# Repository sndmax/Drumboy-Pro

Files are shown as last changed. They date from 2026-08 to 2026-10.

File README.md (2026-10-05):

# Drumboy Pro

📖 **[Developer Wiki](https://www.randomwaves.io/drumboy-pro/drumboy-pro-wiki.html)** — full hardware specs, schematics walkthrough, firmware architecture, DSP internals, and memory map.

**An open-source hardware groovebox** — sequencer, sampler, and DSP effects engine built around an STM32H723 (Cortex-M7 @ 550 MHz), with a 540×960 touch-free color display, 42 keys, 8 rotary encoders, and full MIDI/Sync I/O.

This repository holds the complete hardware design (KiCad) and firmware (STM32CubeIDE / C++) for Drumboy Pro, released by [Randomwaves](https://randomwaves.io) as an open hardware/software project.

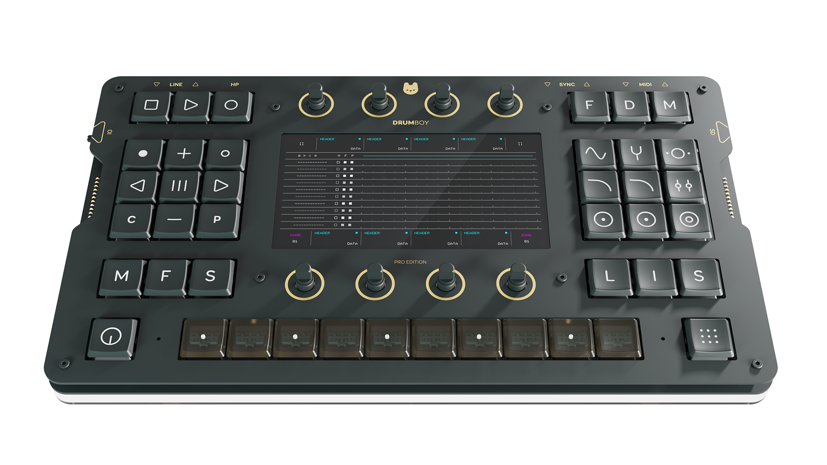
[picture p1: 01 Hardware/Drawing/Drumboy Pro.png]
Drumboy Pro


---

## Overview

The MCU sits at the center of six subsystems: an NT35510 display driven over a 16-bit parallel GPIO bus, 16 MB of external SDRAM for sample streaming, an SGTL5000 audio codec over I2S/I2C, a microSD card for storage, a control surface fanned out over six MCP23017 I/O expanders, and external connectivity (MIDI, Sync, USB-C power).

| | |
|---|---|
| **MCU** | STM32H723ZGT6 — Cortex-M7 @ 550 MHz (VOS0), LQFP-144 |
| **Display** | NT35510, 540×960, 16-bit parallel |
| **SDRAM** | 16 MB (IS42S16800J-7TL-TR), FMC bus |
| **Audio codec** | SGTL5000 — I2S3 audio / I2C3 control |
| **Storage** | microSD (TF-01A), SDMMC2, FAT filesystem |
| **Control surface** | 42 keys, 42 LEDs, 8 rotary encoders — 6× MCP23017 over I2C |
| **Connectivity** | MIDI In/Out, Sync In/Out, USB-C power |
| **Flash** | 1024 KB, split between bootloader and application |

## Features

- **10 sample layers**, each independently modulated by a 10-slot LFO matrix (sample-and-hold at note-trigger time)
- **Per-layer routing** into a shared DSP chain: parametric EQ → 2× multimode filter → 2× send effect → stereo reverb
- **9 effect types** per send slot: Delay, Chorus, Flanger, Phaser, Compressor, Expander, Overdrive, Distortion, Bitcrusher
- **Freeverb/Schroeder-Moorer style reverb** with pre-delay, stereo surround derivation, and nine built-in profiles: Default, Tight, Snap, Chamber, Warehouse, Disco, Dub, Ghost, Texture
- **Sequencer** with 5 song banks per layer, 64 beats per bank, and algorithmic complex-fill generation (timing alignment × level curve templates)
- Hold **Copy** while increasing **Bars** to double the bar count (for example, 2 → 4) and duplicate the entire current song bank across all instruments. Doubling must fit the song-length limit; each bank supports 64 beats and 32 complex fills.
- **MIDI In/Out** (opto-isolated input) and **Sync In/Out** for external clock/gate sync
- **SD-card firmware updates** via a dedicated bootloader with CRC-32 verified staged writes
- Fully open hardware (KiCad) and firmware (C/C++ against the STM32 HAL) — no CMSIS-DSP or external DSP library, all hand-rolled biquad/delay-line DSP on the Cortex-M7 FPU

Choose **Profile** with the second encoder in the Reverb menu or select the field with left/right and change it with up/down. Each profile enables reverb and applies its complete settings through a bypass transition. **Tight** is the starting profile at initialization and for new projects and drumkits. **Default** retains the original settings for an explicit reverb reset and recovery from invalid saved parameters.

| Profile | Intended use | Size | Decay | Damping | PreDelay (ms) | Surround (%) | Dry | Wet |
|---|---|---:|---:|---:|---:|---:|---:|---:|
| Default | Original reset settings | 25 | 50 | 30 | 5 | 25 | 100 | 50 |
| Tight | Techno/house grooves, hats and shakers | 25 | 32 | 65 | 8 | 25 | 100 | 18 |
| Snap | Breakbeat, fast snare/clap and percussion | 10 | 15 | 40 | 10 | 10 | 100 | 18 |
| Chamber | Dark hypnotic percussion, rims and toms | 38 | 55 | 70 | 3 | 30 | 100 | 25 |
| Warehouse | Sparse hits, rides and transitions | 68 | 40 | 60 | 20 | 40 | 100 | 25 |
| Disco | Brighter house/Italo claps, snares and stabs | 40 | 50 | 25 | 20 | 30 | 100 | 30 |
| Dub | Leftfield accents and delay into reverb | 52 | 70 | 75 | 30 | 40 | 100 | 35 |
| Ghost | Wet textures with a shorter tail | 72 | 80 | 70 | 4 | 65 | 0 | 100 |
| Texture | Long atmospheric tails and transitions | 100 | 100 | 65 | 40 | 80 | 0 | 100 |

**Ghost** and **Texture** use Dry 0% / Wet 100% on the shared reverb bus: every source routed into reverb loses its direct signal. For a dedicated texture, route only the intended sources into that bus. Manual edits display **Custom** unless all settings match a built-in profile; the global Size encoder assignment remains available. Projects and drumkits keep the existing file format and restore the profile name from the saved settings. Older Room, Hall, Dark and Ambient settings load as Custom with their parameters preserved.

## Repository structure

```
01 Hardware/
  Main/       KiCad project — main board (Drumboy_Main)
  Top/        KiCad project — top/control-surface board (Drumboy_Top)
  Drawing/    Mechanical drawings, enclosure models, graphics, fonts

02 Software/
  Drumboy-Pro-Boot-H723/   Bootloader — STM32CubeIDE project (own repo, linked below)
  Drumboy-Pro-App-H723/    Application firmware — STM32CubeIDE project (own repo, linked below)
  Firmware/                 Prebuilt firmware binaries
  Sd Card/                  Reference SD card contents (samples, presets, drumkits, system data)
```

### Related repositories

Firmware is split into two independently-built projects that share one flash device — a bad application build can never brick the update path:

| Project | Responsibility |
|---|---|
| [Drumboy-Pro-Boot-H723](https://github.com/Randomwaves-Team/Drumboy-Pro-Boot-H723) | Checks the SD card for a firmware package, validates and programs it, then jumps to the application |
| [Drumboy-Pro-App-H723](https://github.com/Randomwaves-Team/Drumboy-Pro-App-H723) | The sequencer, DSP engine, UI, and all runtime behavior |

## Hardware

Designed in **KiCad 7**. Open `01 Hardware/Main/Drumboy_Main.kicad_pro` for the main board, or `01 Hardware/Top/Drumboy_Top.kicad_pro` for the control-surface board. All third-party symbols, footprints, and 3D models are vendored under each project's `Library/` folder.

Mechanical design (enclosure and 3D model) lives in `01 Hardware/Drawing/` as **Rhinoceros 8** files — `Drumboy Pro 2D.3dm` and `Drumboy Pro 3D.zip` (zipped to keep it under GitHub's file size limit; unzip to get the `.3dm`).

A full BOM is generated from KiCad at `production/bom.csv`. See the [wiki](https://www.randomwaves.io/drumboy-pro/drumboy-pro-wiki.html) for the annotated schematic walkthrough, clock tree, power-domain isolation scheme, and key component reference.

## Firmware

Built with **STM32CubeIDE**, written in C/C++ against the STM32 HAL.

- Bootloader owns flash sector 0 (`0x08000000`–`0x0801FFFF`)
- Application owns sectors 1–7 (`0x08020000`–`0x080FFFFF`), with the vector table relocated at startup

To flash over SWD, wire an ST-Link V2 to the board's `SWDIO` (PA13), `SWCLK` (PA14), and `GND` pins, then build and flash from STM32CubeIDE. See the wiki's [Build, Flash & Debug](https://www.randomwaves.io/drumboy-pro/drumboy-pro-wiki.html) section for details.

## License

Released under the [MIT License](LICENSE).

## Community

- 💬 [Discord community](https://discord.gg/5atevNH6UU) — join the discussion
- 🌐 [randomwaves.io](https://www.randomwaves.io)
- ✉️ [hello@randomwaves.io](mailto:hello@randomwaves.io)

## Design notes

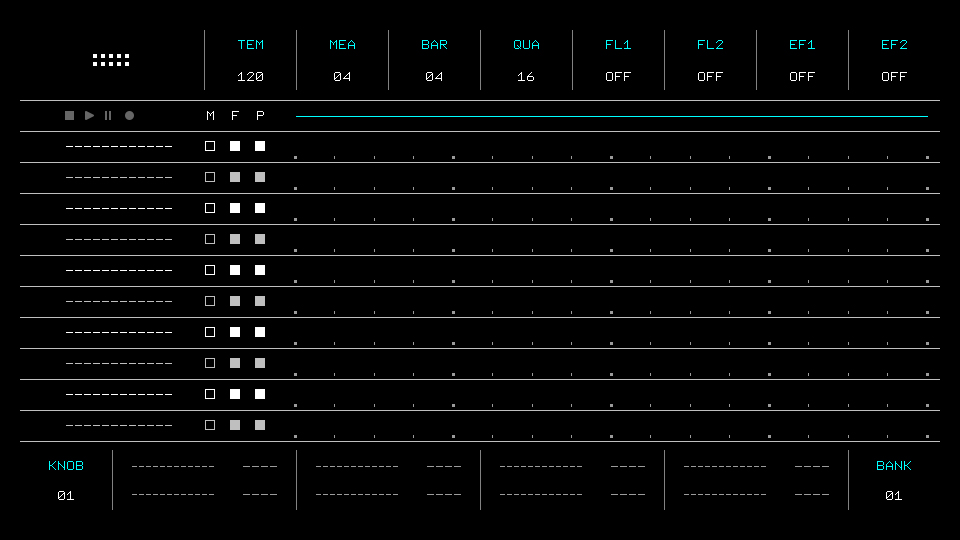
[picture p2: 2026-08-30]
01 Hardware/Drawing/Drumboy Pro Screen.jpg

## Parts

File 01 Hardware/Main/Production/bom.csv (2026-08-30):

Designator | Footprint | Quantity | Value | LCSC Part #
C1, C10, C11, C12, C16, C2, C20, C23, C26, C28, C3, C30, C32, C33, C34, C35, C36, C37, C38, C4, C41, C42, C44, C45, C47, C49, C5, C51, C53, C55, C57, C59, C6, C61, C63, C65, C67, C68, C7, C71, C8, C9 | 603 | 42 | 0.1uF
C13, C17, C27, C29, C31, C39, C48, C50, C52, C54, C56, C58, C72 | 603 | 13 | 4.7uF
C14, C18, C60, C62, C64, C66 | 603 | 6 | 2.2uF
C15, C19 | 603 | 2 | 33pF
C21, C24, C40, C69, C70, C73, C75 | 603 | 7 | 1uF
C22, C25, C43, C46 | 603 | 4 | 10uF
C77, C78, C79, C80, C81, C82, C83, C84, C85, C86, C87, C88, C89, C90, C91, C92 | 603 | 16 | 0.01uF
D1, D2, D3, D39, D4, D40, D41, D42, D43, D44 | 402 | 10 | LED G | C130722
D10 | D_SOD-523 | 1 | 1N4148WT | C27748
D11, D14, D17, D20, D23, D26, D29, D32, D35, D38 | 603 | 10 | LED W | C158100
D12, D13, D15, D16, D18, D19 | 402 | 6 | LED R | C130719
D21, D22, D24, D25, D27, D28, D7, D8 | 402 | 8 | LED O | C130720
D30, D31, D33, D34, D36, D37, D5, D6 | 402 | 8 | LED Y | C130721
D9 | SOD3716X135N | 1 | MBR0520LT3G | C165467
F1 | 805 | 1 | MF-PSMF075X-2 | C116173
FB1, FB2 | 603 | 2 | BLM18AG102SN1D | C85824
FB3, FB4, FB5, FB6, FB7, FB8, FB9 | 603 | 7 | BLM18AG601SN1D | C19330
IC1 | SOP80P1176X120-54N | 1 | IS42S16800J-7TL-TR | C2063470
IC2 | QFP50P2200X2200X160-144N | 1 | STM32H723ZGT6 | C730146
IC3 | SOT95P280X100-5N | 1 | MP3302DJ-LF-Z | C15035
IC4, IC5 | SOT95P285X140-5N | 2 | AP2112K-3.3TRG1 | C51118
IC6 | SOT95P285X140-5N | 1 | AP2112K-1.8TRG1 | C176944
IC7 | QFN50P500X500X90-33N | 1 | SGTL5000XNBA3R2 | C511764
J1 | TYPEC31M17 | 1 | TYPE-C-31-M-17 | C283540
J10, J4, J5, J6, J7, J8, J9 | SJ13515SMTTR | 7 | SJ1-3515-SMT-TR | C92633
J2 | HIROSE_FH26W-51S-0.3SHW_60_ | 1 | FH26W-51S-0.3SHW_60_ | C424656
J3 | M208890345 | 1 | M20-8890345 | C5242196
L1 | NRS5024T4R7MMGJ | 1 | NRS5024T4R7MMGJ | C2043431
MICRO_SD | TF-01A | 1 | TF-01A | C91145
R1, R2 | 603 | 2 | 5.1K
R10, R100, R101, R102, R103, R104, R105, R106, R107, R108, R109, R110, R111, R112, R113, R114, R115, R116, R117, R118, R119, R12, R120, R121, R122, R16, R23, R24, R25, R26, R28, R29, R32, R36, R37, R38, R39, R4, R40, R41, R42, R43, R44, R45, R46, R47, R81, R82, R83, R84, R85, R86, R87, R88, R99 | 603 | 55 | 10K
R11, R14, R17, R20, R56, R57, R6, R60, R61, R64, R65, R67, R68, R70, R71, R73, R74, R76, R77, R79, R8, R80, R9, R90, R91, R93, R94, R95, R96, R97, R98 | 603 | 31 | 2.2K
R13, R7 | 603 | 2 | 100K
R15, R18, R19, R21, R22 | 603 | 5 | 47K
R27 | 603 | 1 | 10
R3, R55, R59, R63, R66, R69, R72, R75, R78, R89, R92 | 603 | 11 | 3.3K
R30, R31, R48 | 603 | 3 | 220
R33, R34, R35, R50, R51, R52, R54 | 603 | 7 | 0
R49 | 603 | 1 | 100
R5 | 603 | 1 | 4.7
R53 | 603 | 1 | 470
R58, R62 | 603 | 2 | 47
S1 | SC12PAQR | 1 | SC12P-AQR | C240300
S2, S3 | 431481031816 | 2 | 431481031816
SW1, SW10, SW11, SW12, SW13, SW14, SW15, SW16, SW17, SW18, SW19, SW2, SW20, SW21, SW22, SW23, SW24, SW25, SW26, SW27, SW28, SW29, SW3, SW30, SW31, SW32, SW33, SW34, SW35, SW36, SW37, SW38, SW39, SW4, SW40, SW41, SW42, SW5, SW6, SW7, SW8, SW9 | SW_PG1350 | 42 | SW_Push
U1, U2, U3, U4, U5, U6 | QFN65P600X600X100-29N-D | 6 | MCP23017_ML | C629439
U10, U11, U12, U13, U14, U15, U8, U9 | PEC12R4017FN0024 | 8 | PEC12R-4017F-N0024
U7 | SMDIP-6_W9.53mm | 1 | H11L1 | C78589
Y1 | ABM7 | 1 | ABM7-8MHZ-D2Y-T | C596892

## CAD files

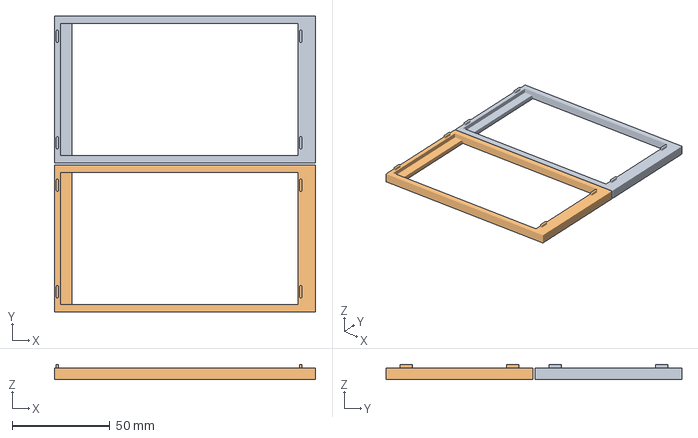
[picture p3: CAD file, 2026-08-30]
01 Hardware/Drawing/Drumboy Pro LCD.3mf
133.5 x 151.4 x 7.80 mm

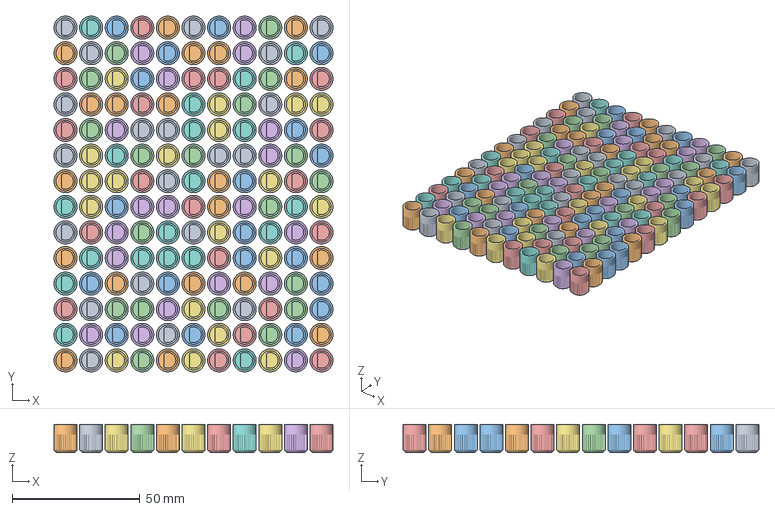
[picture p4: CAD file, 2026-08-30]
01 Hardware/Drawing/Drumboy Pro Knob.3mf
109.0 x 139.0 x 11.0 mm

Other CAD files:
01 Hardware/Drawing/Drumboy Pro 2D.3dm

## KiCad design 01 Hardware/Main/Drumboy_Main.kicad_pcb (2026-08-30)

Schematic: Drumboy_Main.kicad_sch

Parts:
C1, C2, C3, C4, C5, C6, C7, C8, C9, C10, C11, C12, C16, C20, C23, C26, C28, C30, C32, C33, C34, C35, C36, C37, C38, C41, C42, C44, C45, C47, C49, C51, C53, C55, C57, C59, C61, C63, C65, C67, C68, C71: 0.1uF; C_0603_1608Metric
C13, C17, C27, C29, C31, C39, C48, C50, C52, C54, C56, C58, C72: 4.7uF; C_0603_1608Metric
C14, C18, C60, C62, C64, C66: 2.2uF; C_0603_1608Metric
C15, C19: 33pF; C_0603_1608Metric
C21, C24, C40, C69, C70, C73, C75: 1uF; C_0603_1608Metric
C22, C25, C43, C46: 10uF; C_0603_1608Metric
C77, C78, C79, C80, C81, C82, C83, C84, C85, C86, C87, C88, C89, C90, C91, C92: 0.01uF; C_0603_1608Metric
D1, D2, D3, D4, D39, D40, D41, D42, D43, D44: LED G; LED_0402_1005Metric; LCSC Part # C130722
D5, D6, D30, D31, D33, D34, D36, D37: LED Y; LED_0402_1005Metric; LCSC Part # C130721
D7, D8, D21, D22, D24, D25, D27, D28: LED O; LED_0402_1005Metric; LCSC Part # C130720
D9: MBR0520LT3G; SOD3716X135N; Mouser Part Number 863-MBR0520LT3G
D10: 1N4148WT; D_SOD-523; LCSC Part # C27748
D11, D14, D17, D20, D23, D26, D29, D32, D35, D38: LED W; LED_0603_1608Metric; LCSC Part # C158100
D12, D13, D15, D16, D18, D19: LED R; LED_0402_1005Metric; LCSC Part # C130719
F1: MF-PSMF075X-2; Fuse_0805_2012Metric; LCSC Part # C116173
FB1, FB2: BLM18AG102SN1D; L_0603_1608Metric; LCSC Part # C85824
FB3, FB4, FB5, FB6, FB7, FB8, FB9: BLM18AG601SN1D; L_0603_1608Metric; LCSC Part # C19330
IC1: IS42S16800J-7TL-TR; SOP80P1176X120-54N; Manufacturer_Part_Number IS42S16400J-7TL-TR; Mouser Part Number 870-IS42S16400J7TLTR
IC2: STM32H723ZGT6; QFP50P2200X2200X160-144N; Mouser Part Number 511-STM32H723ZGT6
IC3: MP3302DJ-LF-Z; SOT95P280X100-5N; Mouser Part Number 946-MP3302DJLFZ
IC4, IC5: AP2112K-3.3TRG1; SOT95P285X140-5N; Mouser Part Number 621-AP2112K-3.3TRG1
IC6: AP2112K-1.8TRG1; SOT95P285X140-5N; Mouser Part Number 621-AP2112K-1.8TRG1
IC7: SGTL5000XNBA3R2; QFN50P500X500X90-33N; Manufacturer_Part_Number SGTL5000XNBA3R2; Mouser Part Number 771-SGTL5000XNBA3R2
J1: TYPE-C-31-M-17; TYPEC31M17; LCSC Part # C283540
J2: FH26W-51S-0.3SHW_60_; HIROSE_FH26W-51S-0.3SHW_60_; PARTREV DRW NO: EDC3-323714-05; LCSC Part # C424656
J3: M20-8890345; M208890345; Mouser Part Number 855-M20-8890345
J4, J5, J6, J7, J8, J9, J10: SJ1-3515-SMT-TR; SJ13515SMTTR; Mouser Part Number 490-SJ1-3515-SMT-TR
L1: NRS5024T4R7MMGJ; Mouser Part Number 963-NRS5024T4R7MMGJ
MICRO_SD1: TF-01A; LCSC Part # C91145
R1, R2: 5.1K; R_0603_1608Metric
R3, R55, R59, R63, R66, R69, R72, R75, R78, R89, R92: 3.3K; R_0603_1608Metric
R4, R10, R12, R16, R23, R24, R25, R26, R28, R29, R32, R36, R37, R38, R39, R40, R41, R42, R43, R44, R45, R46, R47, R81, R82, R83, R84, R85, R86, R87, R88, R99, R100, R101, R102, R103, R104, R105, R106, R107, R108, R109, R110, R111, R112, R113, R114, R115, R116, R117, R118, R119, R120, R121, R122: 10K; R_0603_1608Metric
R5: 4.7; R_0603_1608Metric
R6, R8, R9, R11, R14, R17, R20, R56, R57, R60, R61, R64, R65, R67, R68, R70, R71, R73, R74, R76, R77, R79, R80, R90, R91, R93, R94, R95, R96, R97, R98: 2.2K; R_0603_1608Metric
R7, R13: 100K; R_0603_1608Metric
R15, R18, R19, R21, R22: 47K; R_0603_1608Metric
R27: 10; R_0603_1608Metric
R30, R31, R48: 220; R_0603_1608Metric
R33, R34, R35, R50, R51, R52, R54: 0; R_0603_1608Metric
R49: 100; R_0603_1608Metric
R53: 470; R_0603_1608Metric
R58, R62: 47; R_0603_1608Metric
S1: SC12P-AQR; SC12PAQR; Manufacturer_Part_Number SC12P-AQR; Mouser Part Number 113-SC12PAQR
S2, S3: 431481031816; PART-NUMBER 431481031816
SW1, SW2, SW3, SW4, SW5, SW6, SW7, SW8, SW9, SW10, SW11, SW12, SW13, SW14, SW15, SW16, SW17, SW18, SW19, SW20, SW21, SW22, SW23, SW24, SW25, SW26, SW27, SW28, SW29, SW30, SW31, SW32, SW33, SW34, SW35, SW36, SW37, SW38, SW39, SW40, SW41, SW42: SW_Push; SW_PG1350; LCSC Part # C400229
U1, U2, U3, U4, U5, U6: MCP23017_ML; QFN65P600X600X100-29N-D; LCSC Part # C629439
U7: H11L1; SMDIP-6_W9.53mm; LCSC Part # C78589
U8, U9, U10, U11, U12, U13, U14, U15: PEC12R-4017F-N0024; PEC12R4017FN0024; Mouser Part Number 652-PEC12R-4017F-N24
Y1: ABM7-8MHZ-D2Y-T; ABM7; Mouser Part Number 815-ABM7-8-D2Y-T

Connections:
+1.8V_DAC: C65.1, C66.1, IC6.5 (VOUT), IC7.30 (VDDD)
+3.3V_DAC: C61.1, C62.1, FB9.1, IC5.5 (VOUT), IC6.1 (VIN), IC6.3 (EN), IC7.20 (VDDIO)
+3.3V_DAC_ANA: C63.1, C64.1, FB9.2, IC7.5 (VDDA)
+3.3V_DIG: C1.1, C2.1, C3.1, C4.1, C5.1, C6.1, C7.1, C8.1, C9.1, C10.1, C11.1, C12.1, C13.1, C16.1, C17.1, C26.1, C27.1, C32.1, C33.1, C34.1, C35.1, C36.1, C37.1, C38.1, C39.1, C43.1, C44.1, C47.1, C48.1, C49.1, C50.1, C51.1, C52.1, C53.1, C54.1, C55.1, C56.1, C57.1, C58.1, C71.1, C72.1, IC1.1 (VDD_1), IC1.3 (VDDQ_1), IC1.9 (VDDQ_2), IC1.14 (VDD_2), IC1.27 (VDD_3), IC1.43 (VDDQ_3), IC1.49 (VDDQ_4), IC2.6 (VBAT), IC2.17 (VDD_1), IC2.30 (VDD_2), IC2.32 (VREF+), IC2.33 (VDDA), IC2.39 (VDD_3), IC2.52 (VDD_4), IC2.62 (VDD_5), IC2.72 (VDD_6), IC2.84 (VDD_7), IC2.95 (VDD33USB), IC2.108 (VDD_8), IC2.121 (VDD_9), IC2.131 (VDD_10), IC2.144 (VDD_11), IC4.5 (VOUT), J2.2, J2.3, MICRO_SD1.4 (VDD), R6.1, R12.2, R15.2, R18.2, R19.2, R21.2, R22.2, R23.2, R24.2, R25.2, R26.2, R28.2, R29.2, R33.2, R36.2, R37.2, R38.2, R39.2, R40.2, R41.2, R42.2, R43.2, R44.2, R45.2, R46.2, R47.2, R53.2, R62.1, R81.2, R82.2, R83.2, R84.2, R99.2, R100.2, R101.2, R102.2, R107.2, R108.2, R109.2, R110.2, R115.2, R116.2, R117.2, R118.2, U1.5 (VDD), U1.11 (A0), U1.13 (A2), U2.5 (VDD), U3.5 (VDD), U3.11 (A0), U4.5 (VDD), U4.12 (A1), U5.5 (VDD), U5.11 (A0), U5.12 (A1), U6.5 (VDD), U6.13 (A2), U7.6; also elsewhere on the board
+5V: C23.1, C24.1, C25.1, FB3.1, FB5.1, FB7.1, S1.C1 (C1_NO)
+5V_BUS: C20.1, C21.1, C22.1, FB1.2, S1.B1 (B1_COM)
+5V_DAC: C59.1, C60.1, FB7.2, IC5.1 (VIN), IC5.3 (EN)
+5V_DIG: C45.1, C46.1, FB3.2, IC4.1 (VIN), R3.1, R32.1
+5V_LCD: C28.1, C29.1, FB5.2, L1.1, R27.1
+5V_USB: F1.1, J1.A9 (VBUS_1), J1.B9 (VBUS_2)
BL_EN: IC3.4 (EN), R4.2, R7.2
BL_GND: IC3.3 (FB), J2.45, J2.46, J2.47, J2.48, J2.49, R5.1
BL_IN: C40.1, IC3.5 (IN), R27.2
BL_SW: D9.2 (A), IC3.1 (SW), L1.2
BL_VCC: C30.1, C31.1, D9.1 (K), J2.50, J2.51
BOOT0: IC2.138 (BOOT0), R16.1
BUTTON: IC2.22 (PF10), R31.2
ENCO_0A: C77.1, IC2.1 (PE2), R85.2
ENCO_0B: C78.1, IC2.5 (PE6), R86.2
ENCO_1A: C81.1, IC2.2 (PE3), R103.2
ENCO_1B: C82.1, IC2.41 (PA5), R104.2
ENCO_2A: C85.1, IC2.3 (PE4), R111.2
ENCO_2B: C86.1, IC2.42 (PA6), R112.2
ENCO_3A: C89.1, IC2.4 (PE5), R119.2
ENCO_3B: C90.1, IC2.43 (PA7), R120.2
ENCO_4A: C79.1, IC2.91 (PG6), R87.2
ENCO_4B: C80.1, IC2.87 (PG2), R88.2
ENCO_5A: C83.1, IC2.92 (PG7), R105.2
ENCO_5B: C84.1, IC2.88 (PG3), R106.2
ENCO_6A: C87.1, IC2.20 (PF8), R113.2
ENCO_6B: C88.1, IC2.8 (PC14-OSC32_IN), R114.2
ENCO_7A: C91.1, IC2.21 (PF9), R121.2
ENCO_7B: C92.1, IC2.9 (PC15-OSC32_OUT), R122.2
FMC_A0: IC1.23 (A0), IC2.10 (PF0)
FMC_A1: IC1.24 (A1), IC2.11 (PF1)
FMC_A2: IC1.25 (A2), IC2.12 (PF2)
FMC_A3: IC1.26 (A3), IC2.13 (PF3)
FMC_A4: IC1.29 (A4), IC2.14 (PF4)
FMC_A5: IC1.30 (A5), IC2.15 (PF5)
FMC_A6: IC1.31 (A6), IC2.50 (PF12)
FMC_A7: IC1.32 (A7), IC2.53 (PF13)
FMC_A8: IC1.33 (A8), IC2.54 (PF14)
FMC_A9: IC1.34 (A9), IC2.55 (PF15)
FMC_A10: IC1.22 (A10), IC2.56 (PG0)
FMC_A11: IC1.35 (A11), IC2.57 (PG1)
FMC_BA0: IC1.20 (BA0), IC2.89 (PG4)
FMC_BA1: IC1.21 (BA1), IC2.90 (PG5)
FMC_D0: IC1.2 (DQ0), IC2.85 (PD14)
FMC_D1: IC1.4 (DQ1), IC2.86 (PD15)
FMC_D2: IC1.5 (DQ2), IC2.114 (PD0)
FMC_D3: IC1.7 (DQ3), IC2.115 (PD1)
FMC_D4: IC1.8 (DQ4), IC2.58 (PE7)
FMC_D5: IC1.10 (DQ5), IC2.59 (PE8)
FMC_D6: IC1.11 (DQ6), IC2.60 (PE9)
FMC_D7: IC1.13 (DQ7), IC2.63 (PE10)
FMC_D8: IC1.42 (DQ8), IC2.64 (PE11)
FMC_D9: IC1.44 (DQ9), IC2.65 (PE12)
FMC_D10: IC1.45 (DQ10), IC2.66 (PE13)
FMC_D11: IC1.47 (DQ11), IC2.67 (PE14)
FMC_D12: IC1.48 (DQ12), IC2.68 (PE15)
FMC_D13: IC1.50 (DQ13), IC2.77 (PD8)
FMC_D14: IC1.51 (DQ14), IC2.78 (PD9)
FMC_D15: IC1.53 (DQ15), IC2.79 (PD10)
FMC_NBL0: IC1.15 (LDQM), IC2.141 (PE0)
FMC_NBL1: IC1.39 (UDQM), IC2.142 (PE1)
FMC_SDCKE0: IC1.37 (CKE), IC2.45 (PC5)
FMC_SDCLK: IC1.38 (CLK), IC2.93 (PG8)
FMC_SDNCAS: IC1.17 (~CAS), IC2.132 (PG15)
FMC_SDNE0: IC1.19 (~CS), IC2.44 (PC4)
FMC_SDNRAS: IC1.18 (~RAS), IC2.49 (PF11)
FMC_SDNWE: IC1.16 (~WE), IC2.26 (PC0)
GND: C20.2, C21.2, C22.2, C23.2, C24.2, C25.2, D1.1 (K), D2.1 (K), D3.1 (K), D4.1 (K), D5.1 (K), D6.1 (K), D7.1 (K), D8.1 (K), FB2.2, FB4.1, FB6.1, FB8.1, J3.2
GND_DAC: C59.2, C60.2, C61.2, C62.2, C63.2, C64.2, C65.2, C66.2, C67.2, C68.2, FB8.2, IC5.2 (GND), IC6.2 (GND), IC7.1 (GND_1), IC7.3 (GND_2), IC7.7 (AGND), IC7.31 (CTRL_ADR0_CS), IC7.32 (CTRL_MODE), IC7.33 (GND_3), J9.1 (SLEEVE), J10.1 (SLEEVE)
GND_DIG: C1.2, C2.2, C3.2, C4.2, C5.2, C6.2, C7.2, C8.2, C9.2, C10.2, C11.2, C12.2, C13.2, C14.2, C15.2, C16.2, C17.2, C18.2, C19.2, C26.2, C27.2, C32.2, C33.2, C34.2, C35.2, C36.2, C37.2, C38.2, C39.2, C41.2, C42.2, C43.2, C44.2, C45.2, C46.2, C47.2, C48.2, C49.2, C50.2, C51.2, C52.2, C53.2, C54.2, C55.2, C56.2, C57.2, C58.2, C71.2, C72.2, C77.2, C78.2, C79.2, C80.2, C81.2, C82.2, C83.2, C84.2, C85.2, C86.2, C87.2, C88.2, C89.2, C90.2, C91.2, C92.2, D11.1 (K), D12.1 (K), D13.1 (K), D14.1 (K), D15.1 (K), D16.1 (K), D17.1 (K), D18.1 (K), D19.1 (K), D20.1 (K), D21.1 (K), D22.1 (K), D23.1 (K), D24.1 (K), D25.1 (K), D26.1 (K), D27.1 (K), D28.1 (K), D29.1 (K), D30.1 (K), D31.1 (K), D32.1 (K), D33.1 (K), D34.1 (K), D35.1 (K), D36.1 (K), D37.1 (K), D38.1 (K), D39.1 (K), D40.1 (K), D41.1 (K), D42.1 (K), D43.1 (K), D44.1 (K), FB4.2, IC1.6 (GNDQ_1), IC1.12 (GNDQ_2), IC1.28 (GND_1), IC1.41 (GND_2), IC1.46 (GNDQ_3), IC1.52 (GNDQ_4), IC1.54 (GND_3), IC2.16 (VSS_1), IC2.31 (VSSA), IC2.38 (VSS_2), IC2.51 (VSS_3), IC2.61 (VSS_4), IC2.83 (VSS_5), IC2.94 (VSS_6), IC2.107 (VSS_7), IC2.120 (VSS_8), IC2.130 (VSS_9), IC4.2 (GND), J2.1, J2.8, J2.14, J2.31, J2.32, J2.33, J2.34, J2.35, J2.36, J2.37, J2.38, J2.39, J2.40, J2.41, J2.42, J2.43, MICRO_SD1.6 (VSS), MICRO_SD1.MP1 (SHIELD), MICRO_SD1.MP2 (SHIELD), MICRO_SD1.MP3 (SHIELD), MICRO_SD1.MP4 (SHIELD), R16.2, R34.2, R35.2, R51.1, R54.1, S2.1, S2.2, S3.1, S3.2, SW1.2, SW2.2, SW3.2, SW4.2, SW5.2, SW6.2, SW7.2, SW8.2, SW9.2, SW10.2, SW11.2, SW12.2, SW13.2, SW14.2, SW15.2, SW16.2, SW17.2, SW18.2, SW19.2, SW20.2, SW21.2, SW22.2, SW23.2, SW24.2, SW25.2, SW26.2, SW27.2, SW28.2, SW29.2, SW30.2, SW31.2, SW32.2, SW33.2, SW34.2, SW35.2, SW36.2, SW37.2, SW38.2, SW39.2, SW40.2, SW41.2, SW42.2, U1.6 (VSS), U1.12 (A1), U1.29 (EP), U2.6 (VSS), U2.11 (A0), U2.12 (A1), U2.13 (A2), U2.29 (EP), U3.6 (VSS), U3.12 (A1), U3.13 (A2), U3.29 (EP), U4.6 (VSS), U4.11 (A0), U4.13 (A2), U4.29 (EP), U5.6 (VSS), U5.13 (A2), U5.29 (EP), U6.6 (VSS), U6.11 (A0), U6.12 (A1), U6.29 (EP), U7.5, U8.C1 (COMMON), U9.C1 (COMMON), U10.C1 (COMMON), U11.C1 (COMMON), U12.C1 (COMMON), U13.C1 (COMMON), U14.C1 (COMMON), U15.C1 (COMMON); also elsewhere on the board
GND_LCD: C28.2, C29.2, C30.2, C31.2, C40.2, FB6.2, IC3.2 (GND), R5.2, R7.1, R13.1
GND_USB: FB2.1, J1.A12 (GND_1), J1.B12 (GND_2), R1.2, R2.2
HPHONE_L: IC7.6 (HP_L), R50.1
HPHONE_R: IC7.2 (HP_R), R52.1
HPHONE_VGND: IC7.4 (HP_VGND), J8.1 (SLEEVE)
HP_L: J8.2 (TIP), R50.2
HP_R: J8.3 (RING), R52.2
I2C3_SCL: IC2.100 (PA8), IC7.29 (CTRL_CLK), R23.1, U1.8 (SCK), U2.8 (SCK), U3.8 (SCK)
I2C3_SDA: IC2.99 (PC9), IC7.27 (CTRL_DATA), R25.1, U1.9 (SDA), U2.9 (SDA), U3.9 (SDA)
I2C4_SCL: IC2.81 (PD12), R24.1, U4.8 (SCK), U5.8 (SCK), U6.8 (SCK)
I2C4_SDA: IC2.82 (PD13), R26.1, U4.9 (SDA), U5.9 (SDA), U6.9 (SDA)
I2S3_CK: IC2.111 (PC10), IC7.24 (I2S_SCLK)
I2S3_MCK: IC2.97 (PC7), R49.1
I2S3_MCK_IN: IC7.21 (SYS_MCLK), R49.2
I2S3_SDI: IC2.112 (PC11), IC7.25 (I2S_DOUT)
I2S3_SDO: IC2.113 (PC12), IC7.26 (I2S_DIN)
I2S3_WS: IC2.40 (PA4), IC7.23 (I2S_LRCLK)
LCD_BL: IC2.129 (PG14), R4.1, R10.1
LCD_CS: IC2.116 (PD2), J2.9
LCD_D0: IC2.46 (PB0), J2.15
LCD_D1: IC2.47 (PB1), J2.16
LCD_D2: IC2.48 (PB2), J2.17
LCD_D3: IC2.133 (PB3), J2.18
LCD_D4: IC2.134 (PB4), J2.19
LCD_D5: IC2.135 (PB5), J2.20
LCD_D6: IC2.136 (PB6), J2.21
LCD_D7: IC2.137 (PB7), J2.22
LCD_D8: IC2.139 (PB8), J2.23
LCD_D9: IC2.140 (PB9), J2.24
LCD_D10: IC2.69 (PB10), J2.25
LCD_D11: IC2.70 (PB11), J2.26
LCD_D12: IC2.73 (PB12), J2.27
LCD_D13: IC2.74 (PB13), J2.28
LCD_D14: IC2.75 (PB14), J2.29
LCD_D15: IC2.76 (PB15), J2.30
LCD_IM0: J2.4, R33.1
LCD_IM1: J2.5, R34.1
LCD_IM2: J2.6, R35.1
LCD_PWM: J2.44, R10.2, R13.2
LCD_RD: IC2.117 (PD3), J2.12
LCD_RESET: IC2.128 (PG13), J2.13
LCD_RS: IC2.119 (PD5), J2.10
LCD_WR: IC2.118 (PD4), J2.11
LED0: IC2.27 (PC1), R8.2, R9.2
LED1: IC2.28 (PC2_C), R11.2, R14.2
LED2: IC2.29 (PC3_C), R17.2, R20.2
LED_EQ_A_00: R97.1, U5.17 (GPA0)
LED_EQ_A_01: R95.1, U5.18 (GPA1)
LED_EQ_A_02: R93.1, U5.19 (GPA2)
LED_EQ_A_03: R90.1, U5.20 (GPA3)
LED_EQ_A_04: R79.1, U5.21 (GPA4)
LED_EQ_A_05: R76.1, U5.22 (GPA5)
LED_EQ_A_06: R73.1, U5.23 (GPA6)
LED_EQ_A_07: R70.1, U5.24 (GPA7)
LED_EQ_A_08: R67.1, U5.25 (GPB0)
LED_EQ_A_09: R64.1, U5.26 (GPB1)
LED_EQ_A_10: R60.1, U5.27 (GPB2)
LED_EQ_A_11: R56.1, U5.28 (GPB3)
LED_EQ_B_00: R98.1, U6.17 (GPA0)
LED_EQ_B_01: R96.1, U6.18 (GPA1)
LED_EQ_B_02: R94.1, U6.19 (GPA2)
LED_EQ_B_03: R91.1, U6.20 (GPA3)
LED_EQ_B_04: R80.1, U6.21 (GPA4)
LED_EQ_B_05: R77.1, U6.22 (GPA5)
LED_EQ_B_06: R74.1, U6.23 (GPA6)
LED_EQ_B_07: R71.1, U6.24 (GPA7)
LED_EQ_B_08: R68.1, U6.25 (GPB0)
LED_EQ_B_09: R65.1, U6.26 (GPB1)
LED_EQ_B_10: R61.1, U6.27 (GPB2)
LED_EQ_B_11: R57.1, U6.28 (GPB3)
LED_KEY_00: R55.1, U4.17 (GPA0)
LED_KEY_01: R59.1, U4.18 (GPA1)
LED_KEY_02: R63.1, U4.19 (GPA2)
LED_KEY_03: R66.1, U4.20 (GPA3)
LED_KEY_04: R69.1, U4.21 (GPA4)
LED_KEY_05: R72.1, U4.22 (GPA5)
LED_KEY_06: R75.1, U4.23 (GPA6)
LED_KEY_07: R78.1, U4.24 (GPA7)
LED_KEY_08: R89.1, U4.25 (GPB0)
LED_KEY_09: R92.1, U4.26 (GPB1)
LINEIN_L: C69.1, IC7.14 (LINEIN_L)
LINEIN_R: C70.1, IC7.13 (LINEIN_R)
LINEOUT_L: C73.1, IC7.12 (LINEOUT_L)
LINEOUT_R: C75.1, IC7.11 (LINEOUT_R)
LI_L: C69.2, J9.2 (TIP)
LI_R: C70.2, J9.3 (RING)
LO_L: C73.2, J10.2 (TIP)
LO_R: C75.2, J10.3 (RING)
MIC: C68.1, IC7.15 (MIC)
MIDI_RX: IC2.101 (PA9), R53.1, U7.4
MIDI_RX_A: D10.1 (K), R48.1, U7.1
MIDI_RX_C: D10.2 (A), J6.2 (TIP), U7.2
MIDI_RX_GND: J6.1 (SLEEVE), R51.2
MIDI_RX_SOURCE: J6.3 (RING), R48.2
MIDI_TX: IC2.96 (PC6), R58.1
MIDI_TX_GND: J7.1 (SLEEVE), R54.2
MIDI_TX_SINK: J7.2 (TIP), R58.2
MIDI_TX_SOURCE: J7.3 (RING), R62.2
MX_A_INT: IC2.34 (PA0), R37.1, U2.16 (INTA)
MX_A_RESET: R43.1, U2.14 (~RESET)
MX_B_INT: IC2.35 (PA1), R38.1, U3.16 (INTA)
MX_B_RESET: R44.1, U3.14 (~RESET)
MX_C_INT: R39.1, U4.16 (INTA)
MX_C_RESET: R45.1, U4.14 (~RESET)
MX_D_INT: R40.1, U5.16 (INTA)
MX_D_RESET: R46.1, U5.14 (~RESET)
MX_E_INT: R41.1, U6.16 (INTA)
MX_E_RESET: R47.1, U6.14 (~RESET)
MX_X_INT: IC2.80 (PD11), R36.1, U1.16 (INTA)
MX_X_RESET: R42.1, U1.14 (~RESET)
NRST: IC2.25 (NRST), R30.2
unnamed: C41.1, R28.1, R30.1, S2.3, S2.4
unnamed: C42.1, R29.1, R31.1, S3.3, S3.4
unnamed: D1.2 (A), R3.2
unnamed: D2.2 (A), R6.2
unnamed: D3.2 (A), R8.1
unnamed: D4.2 (A), R9.1
unnamed: D5.2 (A), R11.1
unnamed: D6.2 (A), R14.1
unnamed: D7.2 (A), R17.1
unnamed: D8.2 (A), R20.1
unnamed: D11.2 (A), R55.2
unnamed: D12.2 (A), R56.2
unnamed: D13.2 (A), R57.2
unnamed: D14.2 (A), R59.2
unnamed: D15.2 (A), R60.2
unnamed: D16.2 (A), R61.2
unnamed: D17.2 (A), R63.2
unnamed: D18.2 (A), R64.2
unnamed: D19.2 (A), R65.2
unnamed: D20.2 (A), R66.2
unnamed: D21.2 (A), R67.2
unnamed: D22.2 (A), R68.2
unnamed: D23.2 (A), R69.2
unnamed: D24.2 (A), R70.2
unnamed: D25.2 (A), R71.2
unnamed: D26.2 (A), R72.2
unnamed: D27.2 (A), R73.2
unnamed: D28.2 (A), R74.2
unnamed: D29.2 (A), R75.2
unnamed: D30.2 (A), R76.2
unnamed: D31.2 (A), R77.2
unnamed: D32.2 (A), R78.2
unnamed: D33.2 (A), R79.2
unnamed: D34.2 (A), R80.2
unnamed: D35.2 (A), R89.2
unnamed: D36.2 (A), R90.2
unnamed: D37.2 (A), R91.2
unnamed: D38.2 (A), R92.2
unnamed: D39.2 (A), R93.2
unnamed: D40.2 (A), R94.2
unnamed: D41.2 (A), R95.2
unnamed: D42.2 (A), R96.2
unnamed: D43.2 (A), R97.2
unnamed: D44.2 (A), R98.2
unnamed: F1.2, FB1.1
unnamed: IC4.3 (EN), R32.2
PDR_ON: IC2.143 (PDR_ON), R12.1
PH0: C15.1, IC2.23 (PH0-OSC_IN), Y1.1
PH1: C19.1, IC2.24 (PH1-OSC_OUT), Y1.2
ROT_0A: R81.1, R85.1, U8.A1 (CHANNEL_A)
ROT_0B: R82.1, R86.1, U8.B1 (CHANNEL_B)
ROT_1A: R99.1, R103.1, U10.A1 (CHANNEL_A)
ROT_1B: R100.1, R104.1, U10.B1 (CHANNEL_B)
ROT_2A: R107.1, R111.1, U12.A1 (CHANNEL_A)
ROT_2B: R108.1, R112.1, U12.B1 (CHANNEL_B)
ROT_3A: R115.1, R119.1, U14.A1 (CHANNEL_A)
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

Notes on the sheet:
C130721
DAC
Encoder
VolReg Dig
SDMMC
LED 0402 RED
LED Layer
I2C Address: 0x23
C130719
I2C Address: 0x24
C400229
LED 0402 ORANGE
PG1350 Kaihl Red
LCD
CPU
C130725
STM32
CORE
C130722
LED 0402 YGREEN
Drumboy Pro
I/O Expander
EXT Interrupts 00 A00 SwitchA 01 A01 SwitchB 02 E02 Encoder0 03 E03 Encoder1 04 E04 Encoder2 05 E05 Encoder3 06 G06 Encoder4 07 G07 Encoder5 08 F08 Encoder6 09 F09 Encoder7 10 F10 Button 11 D11 SwitchX 12 --- 13 --- 14 --- 15 A15 SyncIn
I2C Address: 0x21
DIG
I2C Address: 0x14
Sync / Midi
Switch L
SDRAM
LED 0402 YELLOW
USB C
USB
PG1350 Kaihl Black
200mV 40mA
I2C Address: 0x25
Switch R
LED 0402 WHITE
LED Right-EQ
C130720
I2C Address: 0x20

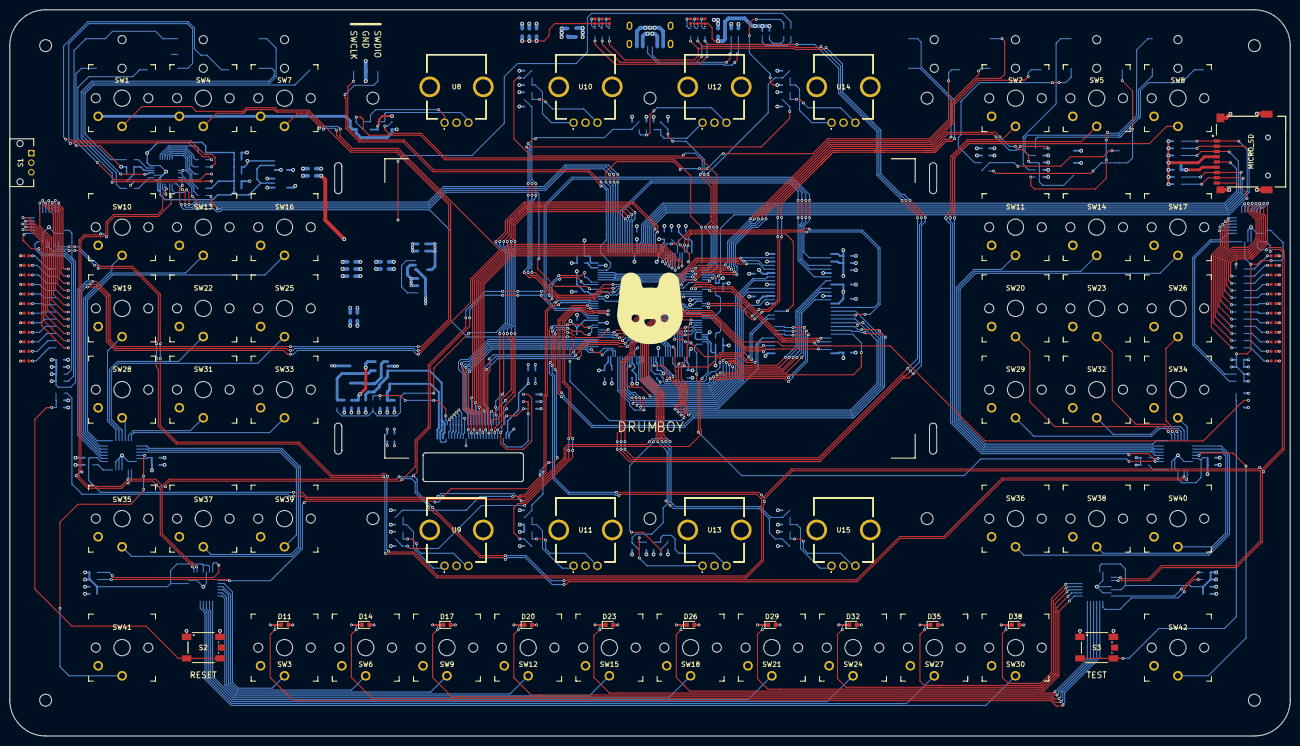
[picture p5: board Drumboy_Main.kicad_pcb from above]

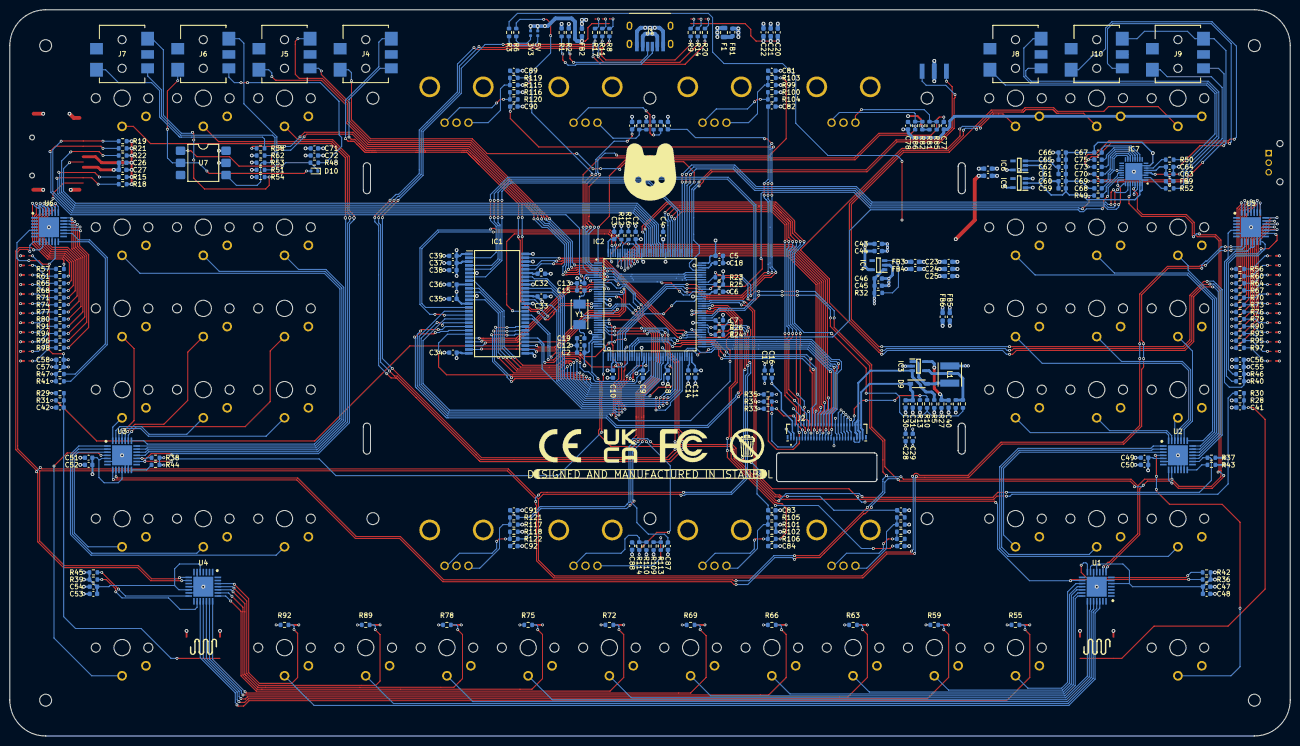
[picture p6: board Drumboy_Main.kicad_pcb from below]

Board: 4 copper layers, 268.0 x 152.0 mm, 346 parts (252 on the bottom side), 312 nets.

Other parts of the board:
MICRO_SD: TF-01A

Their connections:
+3.3V_DIG: MICRO_SD.4 (VDD); also elsewhere on the board
GND_DIG: MICRO_SD.6 (VSS), MICRO_SD.MP1 (SHIELD), MICRO_SD.MP2 (SHIELD), MICRO_SD.MP3 (SHIELD), MICRO_SD.MP4 (SHIELD); also elsewhere on the board
SDMMC2_CK: MICRO_SD.5 (CLK); also elsewhere on the board
SDMMC2_CMD: MICRO_SD.3 (CMD); also elsewhere on the board
SDMMC2_D0: MICRO_SD.7 (DAT0); also elsewhere on the board
SDMMC2_D1: MICRO_SD.8 (DAT1); also elsewhere on the board
SDMMC2_D2: MICRO_SD.1 (DAT2); also elsewhere on the board
SDMMC2_D3: MICRO_SD.2 (CD/DAT3); also elsewhere on the board
SDMMC2_DETECT: MICRO_SD.CD1 (CD); also elsewhere on the board

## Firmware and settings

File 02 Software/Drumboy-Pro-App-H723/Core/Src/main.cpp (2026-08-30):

#include "main.h"

#include "Controller.h"
#include "bdma.h"
#include "dma.h"
#include "fatfs.h"
#include "fmc.h"
#include "gpio.h"
#include "i2c.h"
#include "i2s.h"
#include "sdmmc.h"
#include "tim.h"
#include "usart.h"

/* Extern Function Declarations ---------------------------------- */

extern "C" void SystemClock_Config();
extern "C" void PeriphCommonClock_Config();
extern "C" void Sdram_Initialize();
extern "C" void System_Initialize();

/* Memory Allocation In D1 Ram ----------------------------------- */

uint32_t i2s_rxBuffer[I2S_TOTAL_BUFFER_SIZE] = {0x00};
uint32_t i2s_txBuffer[I2S_TOTAL_BUFFER_SIZE] = {0x00};

/* Memory Allocation In D3 Ram ----------------------------------- */

__attribute__((section(".RAM_D3"))) uint8_t i2c3_rxData[2] = {0x00};
__attribute__((section(".RAM_D3"))) uint8_t i2c3_txData[2] = {0x00};
__attribute__((section(".RAM_D3"))) uint8_t i2c4_rxData[2] = {0x00};
__attribute__((section(".RAM_D3"))) uint8_t i2c4_txData[2] = {0x00};

/* Sync And Midi Buffers ----------------------------------------- */

uint8_t midiRxData;

/* Global Controller Instance ------------------------------------ */

Controller controller;

int main() {
    // System Startup
    __disable_irq();
    SCB->VTOR = APPLICATION_ADDRESS;
    SCB_InvalidateICache();
    SCB_InvalidateDCache();
    SCB_EnableICache();
    HAL_Init();

    // Enable FPU (Floating Point Unit)
    SCB->CPACR |= ((3UL << 10 * 2) | (3UL << 11 * 2));

    // Enable Hardware FTZ (Flush-to-Zero)
    __set_FPSCR(__get_FPSCR() | (1 << 24) | (1 << 25));
    __enable_irq();

    // Configure Clocks
    SystemClock_Config();
    PeriphCommonClock_Config();

    // Initialize Hardware
    System_Initialize();
    Sdram_Initialize();

    // Initialize Application
    controller.initialize();

    // Main Loop
    while (true) {
        controller.update();
    }
}

extern "C" void SystemClock_Config(void) {
    RCC_OscInitTypeDef RCC_OscInitStruct = {0};
    RCC_ClkInitTypeDef RCC_ClkInitStruct = {0};

    /** Supply configuration update enable
     */
    HAL_PWREx_ConfigSupply(PWR_LDO_SUPPLY);

    /** Configure the main internal regulator output voltage
     */
    __HAL_PWR_VOLTAGESCALING_CONFIG(PWR_REGULATOR_VOLTAGE_SCALE0);

    while (!__HAL_PWR_GET_FLAG(PWR_FLAG_VOSRDY)) {
    }

    /** Initializes the RCC Oscillators according to the specified parameters
     * in the RCC_OscInitTypeDef structure.
     */
    RCC_OscInitStruct.OscillatorType = RCC_OSCILLATORTYPE_HSE;
    RCC_OscInitStruct.HSEState = RCC_HSE_ON;
    RCC_OscInitStruct.PLL.PLLState = RCC_PLL_ON;
    RCC_OscInitStruct.PLL.PLLSource = RCC_PLLSOURCE_HSE;
    RCC_OscInitStruct.PLL.PLLM = 1;
    RCC_OscInitStruct.PLL.PLLN = 68;
    RCC_OscInitStruct.PLL.PLLP = 1;
    RCC_OscInitStruct.PLL.PLLQ = 3;
    RCC_OscInitStruct.PLL.PLLR = 2;
    RCC_OscInitStruct.PLL.PLLRGE = RCC_PLL1VCIRANGE_3;
    RCC_OscInitStruct.PLL.PLLVCOSEL = RCC_PLL1VCOWIDE;
    RCC_OscInitStruct.PLL.PLLFRACN = 6144;
    if (HAL_RCC_OscConfig(&RCC_OscInitStruct) != HAL_OK) {
        Error_Handler();
    }

    /** Initializes the CPU, AHB and APB buses clocks
     */
    RCC_ClkInitStruct.ClockType = RCC_CLOCKTYPE_HCLK | RCC_CLOCKTYPE_SYSCLK | RCC_CLOCKTYPE_PCLK1 | RCC_CLOCKTYPE_PCLK2 | RCC_CLOCKTYPE_D3PCLK1 | RCC_CLOCKTYPE_D1PCLK1;
    RCC_ClkInitStruct.SYSCLKSource = RCC_SYSCLKSOURCE_PLLCLK;
    RCC_ClkInitStruct.SYSCLKDivider = RCC_SYSCLK_DIV1;
    RCC_ClkInitStruct.AHBCLKDivider = RCC_HCLK_DIV2;
    RCC_ClkInitStruct.APB3CLKDivider = RCC_APB3_DIV2;
    RCC_ClkInitStruct.APB1CLKDivider = RCC_APB1_DIV2;
    RCC_ClkInitStruct.APB2CLKDivider = RCC_APB2_DIV2;
    RCC_ClkInitStruct.APB4CLKDivider = RCC_APB4_DIV2;

    if (HAL_RCC_ClockConfig(&RCC_ClkInitStruct, FLASH_LATENCY_3) != HAL_OK) {
        Error_Handler();
    }

    /** Enables the Clock Security System
     */
    HAL_RCC_EnableCSS();
}

extern "C" void PeriphCommonClock_Config(void) {
    RCC_PeriphCLKInitTypeDef PeriphClkInitStruct = {0};

    /** Initializes the peripherals clock
     */
    PeriphClkInitStruct.PeriphClockSelection = RCC_PERIPHCLK_FMC | RCC_PERIPHCLK_SDMMC;
    PeriphClkInitStruct.PLL2.PLL2M = 1;
    PeriphClkInitStruct.PLL2.PLL2N = 30;
    PeriphClkInitStruct.PLL2.PLL2P = 1;
    PeriphClkInitStruct.PLL2.PLL2Q = 2;
    PeriphClkInitStruct.PLL2.PLL2R = 1;
    PeriphClkInitStruct.PLL2.PLL2RGE = RCC_PLL2VCIRANGE_3;
    PeriphClkInitStruct.PLL2.PLL2VCOSEL = RCC_PLL2VCOWIDE;
    PeriphClkInitStruct.PLL2.PLL2FRACN = 0;
    PeriphClkInitStruct.FmcClockSelection = RCC_FMCCLKSOURCE_PLL2;
    PeriphClkInitStruct.SdmmcClockSelection = RCC_SDMMCCLKSOURCE_PLL2;
    if (HAL_RCCEx_PeriphCLKConfig(&PeriphClkInitStruct) != HAL_OK) {
        Error_Handler();
    }
}

extern "C" void System_Initialize() {
    // Initialize HAL Modules
    MX_GPIO_Init();
    MX_DMA_Init();
    MX_BDMA_Init();
    MX_FMC_Init();
    MX_FATFS_Init();
    MX_I2C3_Init();
    MX_I2C4_Init();
    MX_I2S3_Init();
    // MX_SDMMC2_SD_Init();
    MX_USART1_UART_Init();
    MX_USART6_UART_Init();
    MX_TIM4_Init();
    MX_TIM5_Init();
    MX_TIM6_Init();
    MX_TIM7_Init();
    MX_TIM8_Init();
    MX_TIM12_Init();
    MX_TIM13_Init();
    MX_TIM14_Init();
    MX_TIM15_Init();
    MX_TIM16_Init();
    MX_TIM17_Init();
    MX_TIM23_Init();
    MX_TIM24_Init();
}

extern "C" void Sdram_Initialize() {
    // Configure Sdram
    SDRAM_HandleTypeDef* hsdram = &hsdram1;
    FMC_SDRAM_CommandTypeDef Command;
    __IO uint32_t tmpmrd = 0;

    // 1. Clock Enable
    Command.CommandMode = FMC_SDRAM_CMD_CLK_ENABLE;
    Command.CommandTarget = FMC_SDRAM_CMD_TARGET_BANK1;
    Command.AutoRefreshNumber = 1;
    Command.ModeRegisterDefinition = 0;
    HAL_SDRAM_SendCommand(hsdram, &Command, SDRAM_TIMEOUT);
    HAL_Delay(1);

    // 2. Precharge All
    Command.CommandMode = FMC_SDRAM_CMD_PALL;
    Command.CommandTarget = FMC_SDRAM_CMD_TARGET_BANK1;
    Command.AutoRefreshNumber = 1;
    Command.ModeRegisterDefinition = 0;
    HAL_SDRAM_SendCommand(hsdram, &Command, SDRAM_TIMEOUT);

    // 3. Auto Refresh
    Command.CommandMode = FMC_SDRAM_CMD_AUTOREFRESH_MODE;
    Command.CommandTarget = FMC_SDRAM_CMD_TARGET_BANK1;
    Command.AutoRefreshNumber = 4;
    Command.ModeRegisterDefinition = 0;
    HAL_SDRAM_SendCommand(hsdram, &Command, SDRAM_TIMEOUT);

    // 4. Load Mode Register
    tmpmrd = (uint32_t)SDRAM_MODEREG_BURST_LENGTH_2 | SDRAM_MODEREG_BURST_TYPE_SEQUENTIAL | SDRAM_MODEREG_CAS_LATENCY_2 | SDRAM_MODEREG_OPERATING_MODE_STANDARD | SDRAM_MODEREG_WRITEBURST_MODE_SINGLE;
    Command.CommandMode = FMC_SDRAM_CMD_LOAD_MODE;
    Command.CommandTarget = FMC_SDRAM_CMD_TARGET_BANK1;
    Command.AutoRefreshNumber = 1;
    Command.ModeRegisterDefinition = tmpmrd;
    HAL_SDRAM_SendCommand(hsdram, &Command, SDRAM_TIMEOUT);

    // 5. Set Refresh Rate
    HAL_SDRAM_ProgramRefreshRate(hsdram, 1854);
}

/* Gpio Interrupts ----------------------------------------------- */

void HAL_GPIO_EXTI_Callback(uint16_t GPIO_Pin) {
    if (controller.getMenu() != INIT_MENU) {
        switch (GPIO_Pin) {
            case MX_X_INT_Pin:
                controller.interruptLayerKeypadRead();
                break;
            case MX_A_INT_Pin:
                controller.interruptLeftKeypadRead();
                break;
            case MX_B_INT_Pin:
                controller.interruptRightKeypadRead();
                break;
            case ENCO_0A_Pin:
                controller.interruptEncoderRead(0);
                break;
            case ENCO_1A_Pin:
                controller.interruptEncoderRead(1);
                break;
            case ENCO_2A_Pin:
                controller.interruptEncoderRead(2);
                break;
            case ENCO_3A_Pin:
                controller.interruptEncoderRead(3);
                break;
            case ENCO_4A_Pin:
                controller.interruptEncoderRead(4);
                break;
            case ENCO_5A_Pin:
                controller.interruptEncoderRead(5);
                break;
            case ENCO_6A_Pin:
                controller.interruptEncoderRead(6);
                break;
            case ENCO_7A_Pin:
                controller.interruptEncoderRead(7);
                break;
            case BUTTON_Pin:
                controller.interruptFuncButtonRead();
                break;
            case SYNC_IN_PULSE_Pin:
                controller.interruptSyncInPulse();
                break;
        }
    }
}

/* Timer Interrupts ---------------------------------------------- */

void HAL_TIM_PeriodElapsedCallback(TIM_HandleTypeDef* htim) {
    if (htim->Instance == TIM4) controller.interruptMidiTxClock();
    if (htim->Instance == TIM5) controller.interruptTransition();
    if (htim->Instance == TIM6) controller.interruptSystemPreset();
    if (htim->Instance == TIM7) controller.interruptEncoderPreset();
    if (htim->Instance == TIM8) controller.interruptLedEq();
    if (htim->Instance == TIM12) controller.interruptUpKeyRead();
    if (htim->Instance == TIM13) controller.interruptDownKeyRead();
    if (htim->Instance == TIM14) controller.interruptLongKeyRead();
    if (htim->Instance == TIM15) controller.interruptPlay();
    if (htim->Instance == TIM16) controller.interruptText();
    if (htim->Instance == TIM17) controller.interruptSd();
    if (htim->Instance == TIM23) controller.interruptBeatSync();
    if (htim->Instance == TIM24) controller.interruptLimitAlert();
}

void HAL_TIM_ErrorCallback(TIM_HandleTypeDef* htim) {}

/* I2s Interrupts ------------------------------------------------ */

// 1. Half Transfer (Process First 32 Samples)
void HAL_I2SEx_TxRxHalfCpltCallback(I2S_HandleTypeDef* hi2s) {
    if (hi2s->Instance == SPI3) {
        controller.processAudioBlock(&i2s_rxBuffer[0], &i2s_txBuffer[0]);
    }
}

// 2. Complete Transfer (Process Second 32 Samples)
void HAL_I2SEx_TxRxCpltCallback(I2S_HandleTypeDef* hi2s) {
    if (hi2s->Instance == SPI3) {
        controller.processAudioBlock(&i2s_rxBuffer[I2S_BLOCK_SIZE * 2], &i2s_txBuffer[I2S_BLOCK_SIZE * 2]);
    }
}

void HAL_I2SEx_TxRxErrorCallback(I2S_HandleTypeDef* hi2s) {
    if (hi2s->Instance == SPI3) {
    }
}

/* I2c Interrupts ------------------------------------------------ */

void HAL_I2C_MemTxCpltCallback(I2C_HandleTypeDef* hi2c) {
    if (hi2c->Instance == I2C3) {
    }
    if (hi2c->Instance == I2C4) {
    }
}

void HAL_I2C_MemRxCpltCallback(I2C_HandleTypeDef* hi2c) {
    if (hi2c->Instance == I2C3) {
    }
    if (hi2c->Instance == I2C4) {
    }
}

void HAL_I2C_ErrorCallback(I2C_HandleTypeDef* hi2c) {}

/* Uart Interrupts ----------------------------------------------- */

void HAL_UART_TxCpltCallback(UART_HandleTypeDef* huart) {
    if (huart == &huart6) {
        controller.serviceMidiTx();
    }
}

void HAL_UART_RxCpltCallback(UART_HandleTypeDef* huart) {
    if (huart == &huart1) {
        controller.receiveMidiCommand();
        HAL_UART_Receive_DMA(&huart1, &midiRxData, 1);
    }
}

void HAL_UART_ErrorCallback(UART_HandleTypeDef* huart) {
    if (huart == &huart1) {
        HAL_UART_Receive_DMA(&huart1, &midiRxData, 1);
    }
}

void Error_Handler(void) {
    __disable_irq();
    while (1) {
    }
}

#ifdef USE_FULL_ASSERT
void assert_failed(uint8_t* file, uint32_t line) {}
#endif

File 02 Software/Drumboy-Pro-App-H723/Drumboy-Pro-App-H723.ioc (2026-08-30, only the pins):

Mcu.UserName=STM32H723ZGTx
PA0.GPIO_Label=MX_A_INT
PA0.Signal=GPXTI0
PA1.GPIO_Label=MX_B_INT
PA1.Signal=GPXTI1
PA10.GPIO_Label=SYNC_OUT_PULSE
PA10.Signal=GPIO_Output
PA11.GPIO_Label=SYNC_OUT_GND
PA11.Signal=GPIO_Output
PA12.GPIO_Label=SYNC_OUT_GATE
PA12.Signal=GPIO_Output
PA13(JTMS/SWDIO).Signal=DEBUG_JTMS-SWDIO
PA14(JTCK/SWCLK).Signal=DEBUG_JTCK-SWCLK
PA15(JTDI).GPIO_Label=SYNC_IN_PULSE
PA15(JTDI).Signal=GPXTI15
PA4.Signal=I2S3_WS
PA5.GPIO_Label=ENCO_1B
PA5.Signal=GPIO_Input
PA6.GPIO_Label=ENCO_2B
PA6.Signal=GPIO_Input
PA7.GPIO_Label=ENCO_3B
PA7.Signal=GPIO_Input
PA8.Signal=I2C3_SCL
PA9.GPIO_Label=MIDI_RX
PA9.Signal=USART1_TX
PB0.GPIO_Label=LCD_D0
PB0.Signal=GPIO_Output
PB1.GPIO_Label=LCD_D1
PB1.Signal=GPIO_Output
PB10.GPIO_Label=LCD_D10
PB10.Signal=GPIO_Output
PB11.GPIO_Label=LCD_D11
PB11.Signal=GPIO_Output
PB12.GPIO_Label=LCD_D12
PB12.Signal=GPIO_Output
PB13.GPIO_Label=LCD_D13
PB13.Signal=GPIO_Output
PB14.GPIO_Label=LCD_D14
PB14.Signal=GPIO_Output
PB15.GPIO_Label=LCD_D15
PB15.Signal=GPIO_Output
PB2.GPIO_Label=LCD_D2
PB2.Signal=GPIO_Output
PB3(JTDO/TRACESWO).GPIO_Label=LCD_D3
PB3(JTDO/TRACESWO).Signal=GPIO_Output
PB4(NJTRST).GPIO_Label=LCD_D4
PB4(NJTRST).Signal=GPIO_Output
PB5.GPIO_Label=LCD_D5
PB5.Signal=GPIO_Output
PB6.GPIO_Label=LCD_D6
PB6.Signal=GPIO_Output
PB7.GPIO_Label=LCD_D7
PB7.Signal=GPIO_Output
PB8.GPIO_Label=LCD_D8
PB8.Signal=GPIO_Output
PB9.GPIO_Label=LCD_D9
PB9.Signal=GPIO_Output
PC0.Signal=FMC_SDNWE
PC1.GPIO_Label=LED0
PC1.Signal=GPIO_Output
PC10.Signal=I2S3_CK
PC11.Signal=I2S3_SDI
PC12.Signal=I2S3_SDO
PC13.GPIO_Label=SDMMC2_DETECT
PC13.Signal=GPIO_Input
PC14-OSC32_IN.GPIO_Label=ENCO_6B
PC14-OSC32_IN.Signal=GPIO_Input
PC15-OSC32_OUT.GPIO_Label=ENCO_7B
PC15-OSC32_OUT.Signal=GPIO_Input
PC2_C.GPIO_Label=LED1
PC2_C.Signal=GPIO_Output
PC3_C.GPIO_Label=LED2
PC3_C.Signal=GPIO_Output
PC4.Signal=FMC_SDNE0
PC5.Signal=FMC_SDCKE0
PC6.GPIO_Label=MIDI_TX
PC6.Signal=USART6_TX
PC7.Signal=I2S3_MCK
PC9.Signal=I2C3_SDA
PD0.Signal=FMC_D2_DA2
PD1.Signal=FMC_D3_DA3
PD10.Signal=FMC_D15_DA15
PD11.GPIO_Label=MX_X_INT
PD11.Signal=GPXTI11
PD12.Signal=I2C4_SCL
PD13.Signal=I2C4_SDA
PD14.Signal=FMC_D0_DA0
PD15.Signal=FMC_D1_DA1
PD2.GPIO_Label=LCD_CS
PD2.Signal=GPIO_Output
PD3.GPIO_Label=LCD_RD
PD3.Signal=GPIO_Output
PD4.GPIO_Label=LCD_WR
PD4.Signal=GPIO_Output
PD5.GPIO_Label=LCD_RS
PD5.Signal=GPIO_Output
PD6.Signal=SDMMC2_CK
PD7.Signal=SDMMC2_CMD
PD8.Signal=FMC_D13_DA13
PD9.Signal=FMC_D14_DA14
PE0.Signal=FMC_NBL0
PE1.Signal=FMC_NBL1
PE10.Signal=FMC_D7_DA7
PE11.Signal=FMC_D8_DA8
PE12.Signal=FMC_D9_DA9
PE13.Signal=FMC_D10_DA10
PE14.Signal=FMC_D11_DA11
PE15.Signal=FMC_D12_DA12
PE2.GPIO_Label=ENCO_0A
PE2.Signal=GPXTI2
PE3.GPIO_Label=ENCO_1A
PE3.Signal=GPXTI3
PE4.GPIO_Label=ENCO_2A
PE4.Signal=GPXTI4
PE5.GPIO_Label=ENCO_3A
PE5.Signal=GPXTI5
PE6.GPIO_Label=ENCO_0B
PE6.Signal=GPIO_Input
PE7.Signal=FMC_D4_DA4
PE8.Signal=FMC_D5_DA5
PE9.Signal=FMC_D6_DA6
PF0.Signal=FMC_A0
PF1.Signal=FMC_A1
PF10.GPIO_Label=BUTTON
PF10.Signal=GPXTI10
PF11.Signal=FMC_SDNRAS
PF12.Signal=FMC_A6
PF13.Signal=FMC_A7
PF14.Signal=FMC_A8
PF15.Signal=FMC_A9
PF2.Signal=FMC_A2
PF3.Signal=FMC_A3
PF4.Signal=FMC_A4
PF5.Signal=FMC_A5
PF6.GPIO_Label=SYNC_IN_GATE
PF6.Signal=GPIO_Input
PF7.GPIO_Label=SYNC_IN_GND
PF7.Signal=GPIO_Output
PF8.GPIO_Label=ENCO_6A
PF8.Signal=GPXTI8
PF9.GPIO_Label=ENCO_7A
PF9.Signal=GPXTI9
PG0.Signal=FMC_A10
PG1.Signal=FMC_A11
PG10.Signal=SDMMC2_D1
PG11.Signal=SDMMC2_D2
PG12.Signal=SDMMC2_D3
PG13.GPIO_Label=LCD_RESET
PG13.Signal=GPIO_Output
PG14.GPIO_Label=LCD_BL
PG14.Signal=GPIO_Output
PG15.Signal=FMC_SDNCAS
PG2.GPIO_Label=ENCO_4B
PG2.Signal=GPIO_Input
PG3.GPIO_Label=ENCO_5B
PG3.Signal=GPIO_Input
PG4.Signal=FMC_A14_BA0
PG5.Signal=FMC_A15_BA1
PG6.GPIO_Label=ENCO_4A
PG6.Signal=GPXTI6
PG7.GPIO_Label=ENCO_5A
PG7.Signal=GPXTI7
PG8.Signal=FMC_SDCLK
PG9.Signal=SDMMC2_D0
PH0-OSC_IN.Signal=RCC_OSC_IN
PH1-OSC_OUT.Signal=RCC_OSC_OUT

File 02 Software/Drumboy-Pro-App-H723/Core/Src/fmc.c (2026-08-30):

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

/* Includes ------------------------------------------------------------------*/
#include "fmc.h"

SDRAM_HandleTypeDef hsdram1;

/* FMC initialization function */
void MX_FMC_Init(void)
{
  FMC_SDRAM_TimingTypeDef SdramTiming = {0};

  /** Perform the SDRAM1 memory initialization sequence
  */
  hsdram1.Instance = FMC_SDRAM_DEVICE;
  /* hsdram1.Init */
  hsdram1.Init.SDBank = FMC_SDRAM_BANK1;
  hsdram1.Init.ColumnBitsNumber = FMC_SDRAM_COLUMN_BITS_NUM_9;
  hsdram1.Init.RowBitsNumber = FMC_SDRAM_ROW_BITS_NUM_12;
  hsdram1.Init.MemoryDataWidth = FMC_SDRAM_MEM_BUS_WIDTH_16;
  hsdram1.Init.InternalBankNumber = FMC_SDRAM_INTERN_BANKS_NUM_4;
  hsdram1.Init.CASLatency = FMC_SDRAM_CAS_LATENCY_2;
  hsdram1.Init.WriteProtection = FMC_SDRAM_WRITE_PROTECTION_DISABLE;
  hsdram1.Init.SDClockPeriod = FMC_SDRAM_CLOCK_PERIOD_2;
  hsdram1.Init.ReadBurst = FMC_SDRAM_RBURST_ENABLE;
  hsdram1.Init.ReadPipeDelay = FMC_SDRAM_RPIPE_DELAY_2;
  /* SdramTiming */
  SdramTiming.LoadToActiveDelay = 2;
  SdramTiming.ExitSelfRefreshDelay = 9;
  SdramTiming.SelfRefreshTime = 5;
  SdramTiming.RowCycleDelay = 8;
  SdramTiming.WriteRecoveryTime = 4;
  SdramTiming.RPDelay = 2;
  SdramTiming.RCDDelay = 2;

  if (HAL_SDRAM_Init(&hsdram1, &SdramTiming) != HAL_OK)
  {
    Error_Handler( );
  }

}

static uint32_t FMC_Initialized = 0;

static void HAL_FMC_MspInit(void){
  GPIO_InitTypeDef GPIO_InitStruct = {0};
  if (FMC_Initialized) {
    return;
  }
  FMC_Initialized = 1;

  /* Peripheral clock enable */
  __HAL_RCC_FMC_CLK_ENABLE();

  /** FMC GPIO Configuration
  PF0   ------> FMC_A0
  PF1   ------> FMC_A1
  PF2   ------> FMC_A2
  PF3   ------> FMC_A3
  PF4   ------> FMC_A4
  PF5   ------> FMC_A5
  PC0   ------> FMC_SDNWE
  PC4   ------> FMC_SDNE0
  PC5   ------> FMC_SDCKE0
  PF11   ------> FMC_SDNRAS
  PF12   ------> FMC_A6
  PF13   ------> FMC_A7
  PF14   ------> FMC_A8
  PF15   ------> FMC_A9
  PG0   ------> FMC_A10
  PG1   ------> FMC_A11
  PE7   ------> FMC_D4
  PE8   ------> FMC_D5
  PE9   ------> FMC_D6
  PE10   ------> FMC_D7
  PE11   ------> FMC_D8
  PE12   ------> FMC_D9
  PE13   ------> FMC_D10
  PE14   ------> FMC_D11
  PE15   ------> FMC_D12
  PD8   ------> FMC_D13
  PD9   ------> FMC_D14
  PD10   ------> FMC_D15
  PD14   ------> FMC_D0
  PD15   ------> FMC_D1
  PG4   ------> FMC_BA0
  PG5   ------> FMC_BA1
  PG8   ------> FMC_SDCLK
  PD0   ------> FMC_D2
  PD1   ------> FMC_D3
  PG15   ------> FMC_SDNCAS
  PE0   ------> FMC_NBL0
  PE1   ------> FMC_NBL1
  */
  /* GPIO_InitStruct */
  GPIO_InitStruct.Pin = GPIO_PIN_0|GPIO_PIN_1|GPIO_PIN_2|GPIO_PIN_3
                          |GPIO_PIN_4|GPIO_PIN_5|GPIO_PIN_11|GPIO_PIN_12
                          |GPIO_PIN_13|GPIO_PIN_14|GPIO_PIN_15;
  GPIO_InitStruct.Mode = GPIO_MODE_AF_PP;
  GPIO_InitStruct.Pull = GPIO_NOPULL;
  GPIO_InitStruct.Speed = GPIO_SPEED_FREQ_VERY_HIGH;
  GPIO_InitStruct.Alternate = GPIO_AF12_FMC;

  HAL_GPIO_Init(GPIOF, &GPIO_InitStruct);

  /* GPIO_InitStruct */
  GPIO_InitStruct.Pin = GPIO_PIN_0|GPIO_PIN_4|GPIO_PIN_5;
  GPIO_InitStruct.Mode = GPIO_MODE_AF_PP;
  GPIO_InitStruct.Pull = GPIO_NOPULL;
  GPIO_InitStruct.Speed = GPIO_SPEED_FREQ_VERY_HIGH;
  GPIO_InitStruct.Alternate = GPIO_AF12_FMC;

  HAL_GPIO_Init(GPIOC, &GPIO_InitStruct);

  /* GPIO_InitStruct */
  GPIO_InitStruct.Pin = GPIO_PIN_0|GPIO_PIN_1|GPIO_PIN_4|GPIO_PIN_5
                          |GPIO_PIN_8|GPIO_PIN_15;
  GPIO_InitStruct.Mode = GPIO_MODE_AF_PP;
  GPIO_InitStruct.Pull = GPIO_NOPULL;
  GPIO_InitStruct.Speed = GPIO_SPEED_FREQ_VERY_HIGH;
  GPIO_InitStruct.Alternate = GPIO_AF12_FMC;

  HAL_GPIO_Init(GPIOG, &GPIO_InitStruct);

  /* GPIO_InitStruct */
  GPIO_InitStruct.Pin = GPIO_PIN_7|GPIO_PIN_8|GPIO_PIN_9|GPIO_PIN_10
                          |GPIO_PIN_11|GPIO_PIN_12|GPIO_PIN_13|GPIO_PIN_14
                          |GPIO_PIN_15|GPIO_PIN_0|GPIO_PIN_1;
  GPIO_InitStruct.Mode = GPIO_MODE_AF_PP;
  GPIO_InitStruct.Pull = GPIO_NOPULL;
  GPIO_InitStruct.Speed = GPIO_SPEED_FREQ_VERY_HIGH;
  GPIO_InitStruct.Alternate = GPIO_AF12_FMC;

  HAL_GPIO_Init(GPIOE, &GPIO_InitStruct);

  /* GPIO_InitStruct */
  GPIO_InitStruct.Pin = GPIO_PIN_8|GPIO_PIN_9|GPIO_PIN_10|GPIO_PIN_14
                          |GPIO_PIN_15|GPIO_PIN_0|GPIO_PIN_1;
  GPIO_InitStruct.Mode = GPIO_MODE_AF_PP;
  GPIO_InitStruct.Pull = GPIO_NOPULL;
  GPIO_InitStruct.Speed = GPIO_SPEED_FREQ_VERY_HIGH;
  GPIO_InitStruct.Alternate = GPIO_AF12_FMC;

  HAL_GPIO_Init(GPIOD, &GPIO_InitStruct);

  /* Peripheral interrupt init */
  HAL_NVIC_SetPriority(FMC_IRQn, 0, 2);
  HAL_NVIC_EnableIRQ(FMC_IRQn);
}

void HAL_SDRAM_MspInit(SDRAM_HandleTypeDef* sdramHandle){
  HAL_FMC_MspInit();
}

static uint32_t FMC_DeInitialized = 0;

static void HAL_FMC_MspDeInit(void){
  if (FMC_DeInitialized) {
    return;
  }
  FMC_DeInitialized = 1;
  /* Peripheral clock enable */
  __HAL_RCC_FMC_CLK_DISABLE();

  /** FMC GPIO Configuration
  PF0   ------> FMC_A0
  PF1   ------> FMC_A1
  PF2   ------> FMC_A2
  PF3   ------> FMC_A3
  PF4   ------> FMC_A4
  PF5   ------> FMC_A5
  PC0   ------> FMC_SDNWE
  PC4   ------> FMC_SDNE0
  PC5   ------> FMC_SDCKE0
  PF11   ------> FMC_SDNRAS
  PF12   ------> FMC_A6
  PF13   ------> FMC_A7
  PF14   ------> FMC_A8
  PF15   ------> FMC_A9
  PG0   ------> FMC_A10
  PG1   ------> FMC_A11
  PE7   ------> FMC_D4
  PE8   ------> FMC_D5
  PE9   ------> FMC_D6
  PE10   ------> FMC_D7
  PE11   ------> FMC_D8
  PE12   ------> FMC_D9
  PE13   ------> FMC_D10
  PE14   ------> FMC_D11
  PE15   ------> FMC_D12
  PD8   ------> FMC_D13
  PD9   ------> FMC_D14
  PD10   ------> FMC_D15
  PD14   ------> FMC_D0
  PD15   ------> FMC_D1
  PG4   ------> FMC_BA0
  PG5   ------> FMC_BA1
  PG8   ------> FMC_SDCLK
  PD0   ------> FMC_D2
  PD1   ------> FMC_D3
  PG15   ------> FMC_SDNCAS
  PE0   ------> FMC_NBL0
  PE1   ------> FMC_NBL1
  */

  HAL_GPIO_DeInit(GPIOF, GPIO_PIN_0|GPIO_PIN_1|GPIO_PIN_2|GPIO_PIN_3
                          |GPIO_PIN_4|GPIO_PIN_5|GPIO_PIN_11|GPIO_PIN_12
                          |GPIO_PIN_13|GPIO_PIN_14|GPIO_PIN_15);

  HAL_GPIO_DeInit(GPIOC, GPIO_PIN_0|GPIO_PIN_4|GPIO_PIN_5);

  HAL_GPIO_DeInit(GPIOG, GPIO_PIN_0|GPIO_PIN_1|GPIO_PIN_4|GPIO_PIN_5
                          |GPIO_PIN_8|GPIO_PIN_15);

  HAL_GPIO_DeInit(GPIOE, GPIO_PIN_7|GPIO_PIN_8|GPIO_PIN_9|GPIO_PIN_10
                          |GPIO_PIN_11|GPIO_PIN_12|GPIO_PIN_13|GPIO_PIN_14
                          |GPIO_PIN_15|GPIO_PIN_0|GPIO_PIN_1);

  HAL_GPIO_DeInit(GPIOD, GPIO_PIN_8|GPIO_PIN_9|GPIO_PIN_10|GPIO_PIN_14
                          |GPIO_PIN_15|GPIO_PIN_0|GPIO_PIN_1);

  /* Peripheral interrupt DeInit */
  HAL_NVIC_DisableIRQ(FMC_IRQn);
}

void HAL_SDRAM_MspDeInit(SDRAM_HandleTypeDef* sdramHandle){
  HAL_FMC_MspDeInit();
}
/**
  * @}
  */

/**
  * @}
  */

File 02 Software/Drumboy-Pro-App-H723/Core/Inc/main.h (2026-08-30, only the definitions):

#define ENCO_0A_Pin GPIO_PIN_2
#define ENCO_0A_GPIO_Port GPIOE
#define ENCO_0A_EXTI_IRQn EXTI2_IRQn
#define ENCO_1A_Pin GPIO_PIN_3
#define ENCO_1A_GPIO_Port GPIOE
#define ENCO_1A_EXTI_IRQn EXTI3_IRQn
#define ENCO_2A_Pin GPIO_PIN_4
#define ENCO_2A_GPIO_Port GPIOE
#define ENCO_2A_EXTI_IRQn EXTI4_IRQn
#define ENCO_3A_Pin GPIO_PIN_5
#define ENCO_3A_GPIO_Port GPIOE
#define ENCO_3A_EXTI_IRQn EXTI9_5_IRQn
#define ENCO_0B_Pin GPIO_PIN_6
#define ENCO_0B_GPIO_Port GPIOE
#define SDMMC2_DETECT_Pin GPIO_PIN_13
#define SDMMC2_DETECT_GPIO_Port GPIOC
#define ENCO_6B_Pin GPIO_PIN_14
#define ENCO_6B_GPIO_Port GPIOC
#define ENCO_7B_Pin GPIO_PIN_15
#define ENCO_7B_GPIO_Port GPIOC
#define SYNC_IN_GATE_Pin GPIO_PIN_6
#define SYNC_IN_GATE_GPIO_Port GPIOF
#define SYNC_IN_GND_Pin GPIO_PIN_7
#define SYNC_IN_GND_GPIO_Port GPIOF
#define ENCO_6A_Pin GPIO_PIN_8
#define ENCO_6A_GPIO_Port GPIOF
#define ENCO_6A_EXTI_IRQn EXTI9_5_IRQn
#define ENCO_7A_Pin GPIO_PIN_9
#define ENCO_7A_GPIO_Port GPIOF
#define ENCO_7A_EXTI_IRQn EXTI9_5_IRQn
#define BUTTON_Pin GPIO_PIN_10
#define BUTTON_GPIO_Port GPIOF
#define BUTTON_EXTI_IRQn EXTI15_10_IRQn
#define LED0_Pin GPIO_PIN_1
#define LED0_GPIO_Port GPIOC
#define LED1_Pin GPIO_PIN_2
#define LED1_GPIO_Port GPIOC
#define LED2_Pin GPIO_PIN_3
#define LED2_GPIO_Port GPIOC
#define MX_A_INT_Pin GPIO_PIN_0
#define MX_A_INT_GPIO_Port GPIOA
#define MX_A_INT_EXTI_IRQn EXTI0_IRQn
#define MX_B_INT_Pin GPIO_PIN_1
#define MX_B_INT_GPIO_Port GPIOA
#define MX_B_INT_EXTI_IRQn EXTI1_IRQn
#define ENCO_1B_Pin GPIO_PIN_5
#define ENCO_1B_GPIO_Port GPIOA
#define ENCO_2B_Pin GPIO_PIN_6
#define ENCO_2B_GPIO_Port GPIOA
#define ENCO_3B_Pin GPIO_PIN_7
#define ENCO_3B_GPIO_Port GPIOA
#define LCD_D0_Pin GPIO_PIN_0
#define LCD_D0_GPIO_Port GPIOB
#define LCD_D1_Pin GPIO_PIN_1
#define LCD_D1_GPIO_Port GPIOB
#define LCD_D2_Pin GPIO_PIN_2
#define LCD_D2_GPIO_Port GPIOB
#define LCD_D10_Pin GPIO_PIN_10
#define LCD_D10_GPIO_Port GPIOB
#define LCD_D11_Pin GPIO_PIN_11
#define LCD_D11_GPIO_Port GPIOB
#define LCD_D12_Pin GPIO_PIN_12
#define LCD_D12_GPIO_Port GPIOB
#define LCD_D13_Pin GPIO_PIN_13
#define LCD_D13_GPIO_Port GPIOB
#define LCD_D14_Pin GPIO_PIN_14
#define LCD_D14_GPIO_Port GPIOB
#define LCD_D15_Pin GPIO_PIN_15
#define LCD_D15_GPIO_Port GPIOB
#define MX_X_INT_Pin GPIO_PIN_11
#define MX_X_INT_GPIO_Port GPIOD
#define MX_X_INT_EXTI_IRQn EXTI15_10_IRQn
#define ENCO_4B_Pin GPIO_PIN_2
#define ENCO_4B_GPIO_Port GPIOG
#define ENCO_5B_Pin GPIO_PIN_3
#define ENCO_5B_GPIO_Port GPIOG
#define ENCO_4A_Pin GPIO_PIN_6
#define ENCO_4A_GPIO_Port GPIOG
#define ENCO_4A_EXTI_IRQn EXTI9_5_IRQn
#define ENCO_5A_Pin GPIO_PIN_7
#define ENCO_5A_GPIO_Port GPIOG
#define ENCO_5A_EXTI_IRQn EXTI9_5_IRQn
#define MIDI_TX_Pin GPIO_PIN_6
#define MIDI_TX_GPIO_Port GPIOC
#define MIDI_RX_Pin GPIO_PIN_9
#define MIDI_RX_GPIO_Port GPIOA
#define SYNC_OUT_PULSE_Pin GPIO_PIN_10
#define SYNC_OUT_PULSE_GPIO_Port GPIOA
#define SYNC_OUT_GND_Pin GPIO_PIN_11
#define SYNC_OUT_GND_GPIO_Port GPIOA
#define SYNC_OUT_GATE_Pin GPIO_PIN_12
#define SYNC_OUT_GATE_GPIO_Port GPIOA
#define SYNC_IN_PULSE_Pin GPIO_PIN_15
#define SYNC_IN_PULSE_GPIO_Port GPIOA
#define SYNC_IN_PULSE_EXTI_IRQn EXTI15_10_IRQn
#define LCD_CS_Pin GPIO_PIN_2
#define LCD_CS_GPIO_Port GPIOD
#define LCD_RD_Pin GPIO_PIN_3
#define LCD_RD_GPIO_Port GPIOD
#define LCD_WR_Pin GPIO_PIN_4
#define LCD_WR_GPIO_Port GPIOD
#define LCD_RS_Pin GPIO_PIN_5
#define LCD_RS_GPIO_Port GPIOD
#define LCD_RESET_Pin GPIO_PIN_13
#define LCD_RESET_GPIO_Port GPIOG
#define LCD_BL_Pin GPIO_PIN_14
#define LCD_BL_GPIO_Port GPIOG
#define LCD_D3_Pin GPIO_PIN_3
#define LCD_D3_GPIO_Port GPIOB
#define LCD_D4_Pin GPIO_PIN_4
#define LCD_D4_GPIO_Port GPIOB
#define LCD_D5_Pin GPIO_PIN_5
#define LCD_D5_GPIO_Port GPIOB
#define LCD_D6_Pin GPIO_PIN_6
#define LCD_D6_GPIO_Port GPIOB
#define LCD_D7_Pin GPIO_PIN_7
#define LCD_D7_GPIO_Port GPIOB
#define LCD_D8_Pin GPIO_PIN_8
#define LCD_D8_GPIO_Port GPIOB
#define LCD_D9_Pin GPIO_PIN_9
#define LCD_D9_GPIO_Port GPIOB

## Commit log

2026-08-30 Add hardware design and firmware
    [Drumboy Pro 2D.3dm, Drumboy Pro Knob.3mf, Drumboy Pro LCD.3mf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]
2026-10-05 Bypass EQ, filters, and effects by default

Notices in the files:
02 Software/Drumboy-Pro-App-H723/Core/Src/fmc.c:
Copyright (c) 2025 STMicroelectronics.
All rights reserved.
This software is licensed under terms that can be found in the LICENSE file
